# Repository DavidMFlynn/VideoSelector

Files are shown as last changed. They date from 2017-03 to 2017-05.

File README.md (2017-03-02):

# VideoSelector
Sets camera to monitor connections, RS-232, Extron Electronics MAV 88, PIC16F1847.
Created by David M. Flynn 2017
I could find one, so I built one.
The main pcb and selector switch pcbs are connected by ethernet patch cables.
Each station can select (with a gray code rotory encoder) which cammera to view.
Box 3D has a 3D printable box.

The PCBs are made with kicad.  Two of the wires on port 2 are swapped, fixed in software.
I know its unlikely anyone will want one, but it makes a good example project.

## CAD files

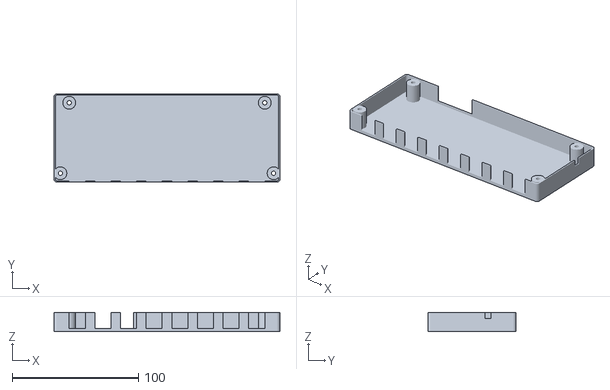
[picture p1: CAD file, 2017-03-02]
Box 3D/ProjectCaseTop.stl
179.1 x 70.1 x 15.2

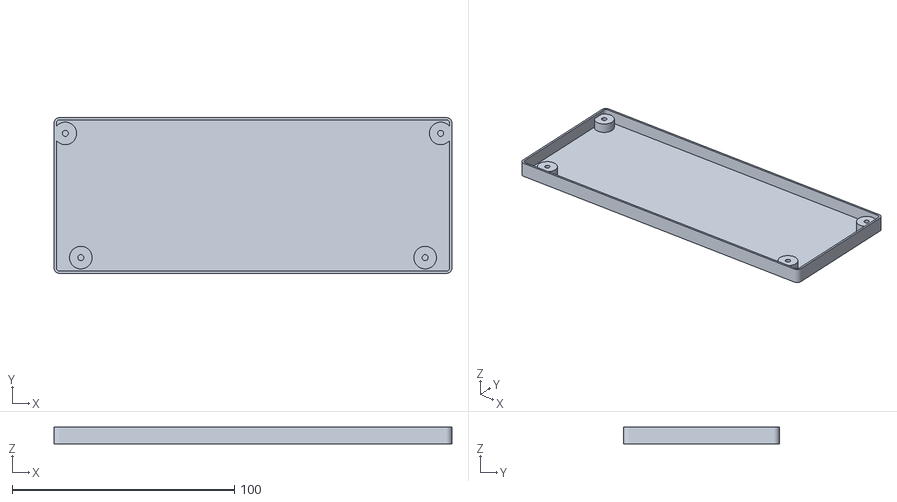
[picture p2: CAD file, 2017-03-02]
Box 3D/ProjectCaseBot.stl
179.1 x 70.1 x 7.62

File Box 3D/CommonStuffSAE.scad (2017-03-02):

// *************************************************
// filename: CommondStuffSAE.scad
//  by Dave Flynn 2015, GPL v2
// Rev: 0.9.1 2/28/2016 Some hole sizes have not been tested.
//
// This file contains constants and some common routines
// Units: Inches
// *************************************************
//  Routines for making bolt holes in parts
//  #2-56
// Bolt2ButtonHeadHole(lDepth=0.3,lHead=0.5);
// Bolt2HeadHole(lDepth=0.3,lHead=0.5);
// Bolt2Hole(depth=0.4);
// Bolt2ClearHole(depth=0.5);
//  #4-40
// Bolt4ButtonHeadHole(lDepth=0.3,lHead=0.5);
// Bolt4HeadHole(lDepth=0.3,lHead=0.5);
// Bolt4Hole(depth=0.5);
// Bolt4ClearHole(depth=0.5);
//  #6-32
// Bolt6ButtonHeadHole(lDepth=0.5,lHead=0.5);
// Bolt6HeadHole(lDepth=0.625, lAccess=0.5);
// Bolt6Hole(depth=0.625);
// Bolt6ClearHole(depth=0.5);
//  #8-32
// Bolt8ButtonHeadHole(lDepth=0.5,lHead=0.5);
// Bolt8HeadHole(lDepth=0.5, lAccess=0.5);
// Bolt8Hole(depth=0.75);
// Bolt8ClearHole(depth=0.5);
//  #10-32, #10-24, M5
// Bolt10ButtonHeadHole(lDepth=0.5,lHead=0.5);
// Bolt10HeadHole(lDepth=0.5, lAccess=0.5);
// Bolt10Hole(depth=0.75);
// Bolt10ClearHole(depth=0.75);
//  1/4"-20
// Bolt250ButtonHeadHole(lDepth=0.5,lHead=0.5);
// Bolt250HeadHole(lDepth=0.5, lAccess=0.5);
// Bolt250Hole(depth=0.75);
// Bolt250ClearHole(depth=0.75);
// *************************************************
// History
// 0.9.1 2/28/2016	Added Bolt6TapHole_r, made Bolt6_r 0.005 smaller
// 0.9 1/30/2016 	First rev'd version, Did a bunck of cleanup
// *************************************************
//ShowAllBolts(); // for visulization
//scale([25.4,25.4,25.4]) HoleTestBlock(); // Print 1 to test fit all bolts

// ********** Constants **********

OverLap=0.004;  // used to ensure manifoldness
Overlap=OverLap;
ID_Xtra=0.004;	// Added to ID to compensate for printing DMF3D

//ID_Xtra=0.008;	// Added to ID to compensate for printing Bukobot 1

Bolt2_r=0.038;
Bolt2_Head_h=0.090;
Bolt2_Head_r=0.060;
Bolt2_BtnHead_r=0.090;
Bolt2_BtnHead_h=0.045;
Bolt2_Clear_r=0.053;

Bolt4_r=0.050;
Bolt4TapHole_r=0.0445;
Bolt4_Head_r=0.091;	
Bolt4_Head_h=0.116;
Bolt4_BtnHead_r=0.120;// 0.015 over so M3 is OK
Bolt4_BtnHead_h=0.066;
Bolt4_Clear_r=0.063;

Bolt6_r=0.058;
Bolt6TapHole_r=0.055;
Bolt6_Head_r=0.125;
Bolt6_Head_h=0.140;
Bolt6_BtnHead_r=0.135;
Bolt6_BtnHead_h=0.075;
Bolt6_Clear_r=0.073;

Bolt8TapHole_r=0.068;
Bolt8_r=0.070;
Bolt8_Head_r=0.145;
Bolt8_Head_h=0.22;
Bolt8_BtnHead_r=0.188;
Bolt8_BtnHead_h=0.095;
Bolt8_Clear_r=0.090;

Bolt10TapHole_r=0.080;
Bolt10_r=0.080; // was 0.094;
Bolt10_Head_r=0.157;
Bolt10_Head_h=0.195;
Bolt10_BtnHead_r=0.190;
Bolt10_BtnHead_h=0.115;
Bolt10_Clear_r=0.105;

Bolt250TapHole_r=0.100;
Bolt250_r=0.110;
Bolt250_Head_r=0.190;
Bolt250_Head_h=0.250;
Bolt250_BtnHead_r=0.210;
Bolt250_BtnHead_h=0.135;
Bolt250_Clear_r=0.128;

// ***** #2-56 *****

module Bolt2ButtonHeadHole(lDepth=0.3,lHead=0.5){
	translate([0,0,-lDepth-Bolt2_BtnHead_h])
		cylinder(r=Bolt2_Clear_r+ID_Xtra,h=lDepth+OverLap,$fn=24);
	translate([0,0,-Bolt2_BtnHead_h])
		cylinder(r=Bolt2_BtnHead_r+ID_Xtra,h=lHead,$fn=24);
} // Bolt2ButtonHeadHole

module Bolt2HeadHole(lDepth=0.3,lHead=0.5){
	translate([0,0,-lDepth-Bolt2_Head_h])
		cylinder(r=Bolt2_Clear_r+ID_Xtra,h=lDepth+OverLap,$fn=24);
	translate([0,0,-Bolt2_Head_h])
		cylinder(r=Bolt2_Head_r+ID_Xtra,h=lHead,$fn=24);
} // Bolt2HeadHole

module Bolt2Hole(depth=0.4){
	translate([0,0,-depth-OverLap])
		cylinder(r=Bolt2_r+ID_Xtra,h=depth+OverLap*2,$fn=24);
} // Bolt2Hole

module Bolt2ClearHole(depth=0.5){
	translate([0,0,-depth-OverLap])
		cylinder(r=Bolt2_Clear_r+ID_Xtra,h=depth+OverLap*2,$fn=24);
} // BoltClearHole

// ***** #4-40 *****

module Bolt4ButtonHeadHole(lDepth=0.3,lHead=0.5){
	translate([0,0,-lDepth-Bolt4_BtnHead_h])
		cylinder(r=Bolt4_Clear_r+ID_Xtra,h=lDepth+OverLap,$fn=24);
	translate([0,0,-Bolt4_BtnHead_h])
		cylinder(r=Bolt4_BtnHead_r+ID_Xtra,h=lHead,$fn=24);
} // Bolt4ButtonHeadHole

module Bolt4HeadHole(lDepth=0.3,lHead=0.5){
	translate([0,0,-lDepth-Bolt4_Head_h])
		cylinder(r=Bolt4_Clear_r+ID_Xtra,h=lDepth+OverLap,$fn=24);
	translate([0,0,-Bolt4_Head_h])
		cylinder(r=Bolt4_Head_r+ID_Xtra,h=lHead,$fn=24);
} // Bolt4HeadHole

module Bolt4Hole(depth=0.5){
	translate([0,0,-depth-OverLap])
		cylinder(r=Bolt4_r+ID_Xtra,h=depth+OverLap*2,$fn=24);
} // Bolt4Hole

module Bolt4ClearHole(depth=0.5){
	translate([0,0,-depth-OverLap])
		cylinder(r=Bolt4_Clear_r+ID_Xtra,h=depth+OverLap*2,$fn=24);
} // BoltClearHole

// ***** #6-32 *****

module Bolt6ButtonHeadHole(lDepth=0.5,lHead=0.5){
	translate([0,0,-lDepth-Bolt6_BtnHead_h])
		cylinder(r=Bolt6_Clear_r+ID_Xtra,h=lDepth+OverLap,$fn=24);
	translate([0,0,-Bolt6_BtnHead_h])
		cylinder(r=Bolt6_BtnHead_r+ID_Xtra,h=lHead,$fn=24);
} // Bolt6ButtonHeadHole

module Bolt6ClearHole(depth=0.5){
	translate([0,0,-depth-OverLap])
		cylinder(r=Bolt6_Clear_r+ID_Xtra,h=depth+OverLap*2,$fn=24);
} // BoltClearHole

module Bolt6Hole(depth=0.625){
	translate([0,0,-depth-OverLap])
		cylinder(r=Bolt6_r+ID_Xtra,h=depth+OverLap*2,$fn=24);
} // BoltClearHole

module Bolt6HeadHole(lDepth=0.625, lAccess=0.5){
	translate([0,0,-lDepth-Bolt6_Head_h])
		cylinder(r=Bolt6_Clear_r+ID_Xtra,h=lDepth+OverLap,$fn=24);
	translate([0,0,-Bolt6_Head_h])
		cylinder(r=Bolt6_Head_r+ID_Xtra,h=Bolt6_Head_h+lAccess+OverLap,$fn=24);
} // Bolt6HeadHole

// ***** #8-32 *****

module Bolt8ButtonHeadHole(lDepth=0.5,lHead=0.5){
	translate([0,0,-lDepth-Bolt8_BtnHead_h])
		cylinder(r=Bolt8_Clear_r+ID_Xtra,h=lDepth+OverLap,$fn=24);
	translate([0,0,-Bolt8_BtnHead_h])
		cylinder(r=Bolt8_BtnHead_r+ID_Xtra,h=lHead,$fn=24);
} // Bolt8ButtonHeadHole

module Bolt8Hole(depth=0.75){
	translate([0,0,-depth-OverLap])
		cylinder(r=Bolt8_r+ID_Xtra,h=depth+OverLap*2,$fn=24);
} // Bolt8Hole

module Bolt8HeadHole(lDepth=0.5, lAccess=0.5){
	translate([0,0,-lDepth-Bolt8_Head_h])
		cylinder(r=Bolt8_Clear_r+ID_Xtra,h=lDepth+OverLap,$fn=24);
	translate([0,0,-Bolt8_Head_h])
		cylinder(r=Bolt8_Head_r+ID_Xtra,h=Bolt8_Head_h+lAccess+OverLap,$fn=24);
} // Bolt8HeadHole

module Bolt8ClearHole(depth=0.5){
	translate([0,0,-depth-OverLap])
		cylinder(r=Bolt8_Clear_r+ID_Xtra,h=depth+OverLap*2,$fn=24);
} // Bolt8Hole

// ***** #10-32, #10-24, M5 *****

module Bolt10ButtonHeadHole(lDepth=0.5,lHead=0.5){
	translate([0,0,-lDepth-Bolt10_BtnHead_h])
		cylinder(r=Bolt10_Clear_r+ID_Xtra,h=lDepth+OverLap,$fn=24);
	translate([0,0,-Bolt10_BtnHead_h])
		cylinder(r=Bolt10_BtnHead_r+ID_Xtra,h=lHead,$fn=24);
} // Bolt10ButtonHeadHole

module Bolt10Hole(depth=0.75){
	translate([0,0,-depth+OverLap])
		cylinder(r=Bolt10_r+ID_Xtra,h=depth+OverLap*2,$fn=24);
} // Bolt10Hole

module Bolt10HeadHole(lDepth=0.5, lAccess=0.5){
	translate([0,0,-lDepth-Bolt10_Head_h])
		cylinder(r=Bolt10_Clear_r+ID_Xtra,h=lDepth+OverLap,$fn=24);
	translate([0,0,-Bolt10_Head_h])
		cylinder(r=Bolt10_Head_r+ID_Xtra,h=Bolt10_Head_h+lAccess+OverLap,$fn=24);
} // Bolt10HeadHole

module Bolt10ClearHole(depth=0.75){
	translate([0,0,-depth+OverLap])
		cylinder(r=Bolt10_Clear_r+ID_Xtra,h=depth+OverLap*2,$fn=24);
} // Bolt10Hole

// ***** 1/4"-20 *****

module Bolt250ButtonHeadHole(lDepth=0.5,lHead=0.5){
	translate([0,0,-lDepth-Bolt250_BtnHead_h])
		cylinder(r=Bolt250_Clear_r+ID_Xtra,h=lDepth+OverLap,$fn=24);
	translate([0,0,-Bolt250_BtnHead_h])
		cylinder(r=Bolt250_BtnHead_r+ID_Xtra,h=lHead,$fn=24);
} // Bolt250ButtonHeadHole

module Bolt250Hole(depth=0.75){
	translate([0,0,-depth+OverLap])
		cylinder(r=Bolt250_r+ID_Xtra,h=depth+OverLap*2,$fn=24);
} // Bolt250ClearHole

module Bolt250ClearHole(depth=0.75){
	translate([0,0,-depth+OverLap])
		cylinder(r=Bolt250_Clear_r+ID_Xtra,h=depth+OverLap*2,$fn=24);
} // Bolt250ClearHole

module Bolt250HeadHole(lDepth=0.5, lAccess=0.5){
	translate([0,0,-lDepth-Bolt250_Head_h])
		cylinder(r=Bolt250_Clear_r+ID_Xtra,h=lDepth+OverLap,$fn=24);
	translate([0,0,-Bolt250_Head_h])
		cylinder(r=Bolt250_Head_r+ID_Xtra,h=Bolt250_Head_h+lAccess+OverLap,$fn=24);
} // Bolt250HeadHole

// **********************************

module ShowAllBolts(){
	translate([0,2.2,0]){ Bolt2ButtonHeadHole();
	translate([0.5,0,0]) Bolt2Hole();
	translate([1,0,0]) Bolt2ClearHole();
	translate([1.5,0,0]) Bolt2HeadHole();}

	translate([0,1.85,0]){ Bolt4ButtonHeadHole();
	translate([0.5,0,0]) Bolt4Hole();
	translate([1,0,0]) Bolt4ClearHole();
	translate([1.5,0,0]) Bolt4HeadHole();}

	translate([0,1.45,0]){ Bolt6ButtonHeadHole();
	translate([0.5,0,0]) Bolt6Hole();
	translate([1,0,0]) Bolt6ClearHole();
	translate([1.5,0,0]) Bolt6HeadHole();}

	translate([0,1,0]){ Bolt8ButtonHeadHole();
	translate([0.5,0,0]) Bolt8Hole();
	translate([1,0,0]) Bolt8ClearHole();
	translate([1.5,0,0]) Bolt8HeadHole();}

	translate([0,0.5,0]){ Bolt10ButtonHeadHole();
	translate([0.5,0,0]) Bolt10Hole();
	translate([1,0,0]) Bolt10ClearHole();
	translate([1.5,0,0]) Bolt10HeadHole();}

	translate([0,0,0]){ Bolt250ButtonHeadHole();
	translate([0.5,0,0]) Bolt250Hole();
	translate([1,0,0]) Bolt250ClearHole();
	translate([1.5,0,0]) Bolt250HeadHole();}
	
} // ShowAllBolts
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

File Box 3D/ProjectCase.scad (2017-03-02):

// **************************************************************
// Project Case (Selector 8 x 16 version)
// Revision: 1.0.0 3/1/2017
// Created: 3/1/2017
// by David M. Flynn
// units: inches
// **************************************************************
// ***** for STL output *****
// scale(25.4) BoxBottom();
// scale(25.4) rotate([180,0,0]) BoxTop();
// **************************************************************
// ***** general routines *****
// RoundRect(X=2.0,Y=1.0,Z=0.5,R=0.1);
// BoxShell(X=2.0,Y=1.0,Z=0.5,R=0.1,Wall=0.04);
// MountingBoss(X=0,Y=0,R=0.2) children;
// **************************************************************

include<CommonStuffSAE.scad>

Overlap=0.005;
IDXtra=0.008;
$fn=90;

module RoundRect(X=2.0,Y=1.0,Z=0.5,R=0.1){
	hull(){
		translate([-X/2+R,-Y/2+R,0]) cylinder(r=R, h=Z);
		translate([X/2-R,-Y/2+R,0]) cylinder(r=R, h=Z);
		translate([-X/2+R,Y/2-R,0]) cylinder(r=R, h=Z);
		translate([X/2-R,Y/2-R,0]) cylinder(r=R, h=Z);
	}// hull
	
} // RoundRect

//RoundRect();

module BoxShell(X=2.0,Y=1.0,Z=0.5,R=0.1,Wall=0.04){
	difference(){
		RoundRect(X=X,Y=Y,Z=Z,R=R);
		translate([0,0,Wall]) RoundRect(X=X-Wall*2,Y=Y-Wall*2,Z=Z,R=R-Wall);
	} // diff
	
	
} // BoxShell

//BoxShell();
PCB_t=0.063;
PCB_x=6.5;
PCB_y=2.6;
MH1=[.2,.2];
MH2=[6.3,.2];
MH3=[-0.075,PCB_y-0.2];
MH4=[PCB_x+0.075,PCB_y-0.2];
BoxWall_t=0.04;
Box_x=PCB_x+0.55;
Box_y=PCB_y+BoxWall_t*4;
BoxBot_h=0.3;
BoxTop_h=0.6;
BoxCorner_r=0.1;

module MountingBoss(X=0,Y=0,R=0.2){
	// from PCB 0,0
	
	difference(){
		translate([-PCB_x/2+X,-PCB_y/2+Y,BoxWall_t-Overlap]) cylinder(r=R,h=BoxBot_h-PCB_t-BoxWall_t);
		translate([-PCB_x/2+X,-PCB_y/2+Y,BoxBot_h-PCB_t]) children();
	} // diff
} // MountingBoss

module PCBRelPos(X=0,Y=0){
	translate([-PCB_x/2+X,-PCB_y/2+Y,0]) children();
} // PCBRelPos

module MountingBossTop(X=0,Y=0,R=0.2){
	// from PCB 0,0
	
	PCBRelPos(X=X,Y=Y)
	difference(){
		cylinder(r=R,h=BoxTop_h-Overlap);
		translate([0,0,BoxTop_h]) children();
	} // diff
} // MountingBossTop

module BoxBottom(){
	BoxShell(X=Box_x,Y=Box_y,Z=BoxBot_h,R=BoxCorner_r,Wall=BoxWall_t);
	MountingBoss(MH1[0],MH1[1],R=0.2) Bolt4Hole();
	MountingBoss(MH2[0],MH2[1],R=0.2) Bolt4Hole();
	MountingBoss(MH3[0],MH3[1],R=0.2) Bolt4Hole();
	MountingBoss(MH4[0],MH4[1],R=0.2) Bolt4Hole();
	
	// pcb
	//translate([-PCB_x/2,-PCB_y/2,BoxBot_h-PCB_t+Overlap]) cube([PCB_x,PCB_y,PCB_t]);
} // BoxBottom

//translate([0,0,-BoxBot_h]) BoxBottom();

RS232=[0.925,2.2,0.5]; // start,end,height
RJ45=[0.45,0.5,0.8,0.5]; // CL first, width, space, height
PowerCord_y=0.8;

module BoxTop(){
	difference(){
		
		translate([0,0,BoxTop_h]) mirror([0,0,1]) BoxShell(X=Box_x,Y=Box_y,Z=BoxTop_h,R=BoxCorner_r,Wall=BoxWall_t);
		
		translate([0,0,BoxTop_h]) {
		PCBRelPos(MH1[0],MH1[1]) Bolt4HeadHole();
		PCBRelPos(MH2[0],MH2[1]) Bolt4HeadHole();
		PCBRelPos(MH3[0],MH3[1]) Bolt4HeadHole();
		PCBRelPos(MH4[0],MH4[1]) Bolt4HeadHole();
		}
		
		translate([-PCB_x/2+RS232[0],-Box_y/2-Overlap,-Overlap]) cube([RS232[1]-RS232[0],BoxWall_t+Overlap*2,RS232[2]]);
		
		translate([-PCB_x/2+RJ45[0]-RJ45[1]/2,Box_y/2-BoxWall_t-Overlap,-Overlap])
			for (j=[0:7]) translate([j*RJ45[2],0,0]) cube([RJ45[1],BoxWall_t+Overlap*2,RJ45[3]]);
				
		translate([Box_x/2-BoxWall_t-Overlap,-PCB_y/2+PowerCord_y-0.1,-Overlap]) cube([BoxWall_t+Overlap*2,0.2,0.2]);
	} // diff
	
	MountingBossTop(MH1[0],MH1[1],R=0.2) Bolt4HeadHole(lDepth=BoxTop_h);
	MountingBossTop(MH2[0],MH2[1],R=0.2) Bolt4HeadHole(lDepth=BoxTop_h);
	MountingBossTop(MH3[0],MH3[1],R=0.2) Bolt4HeadHole(lDepth=BoxTop_h);
	MountingBossTop(MH4[0],MH4[1],R=0.2) Bolt4HeadHole(lDepth=BoxTop_h);

} // BoxTop 

//BoxTop();

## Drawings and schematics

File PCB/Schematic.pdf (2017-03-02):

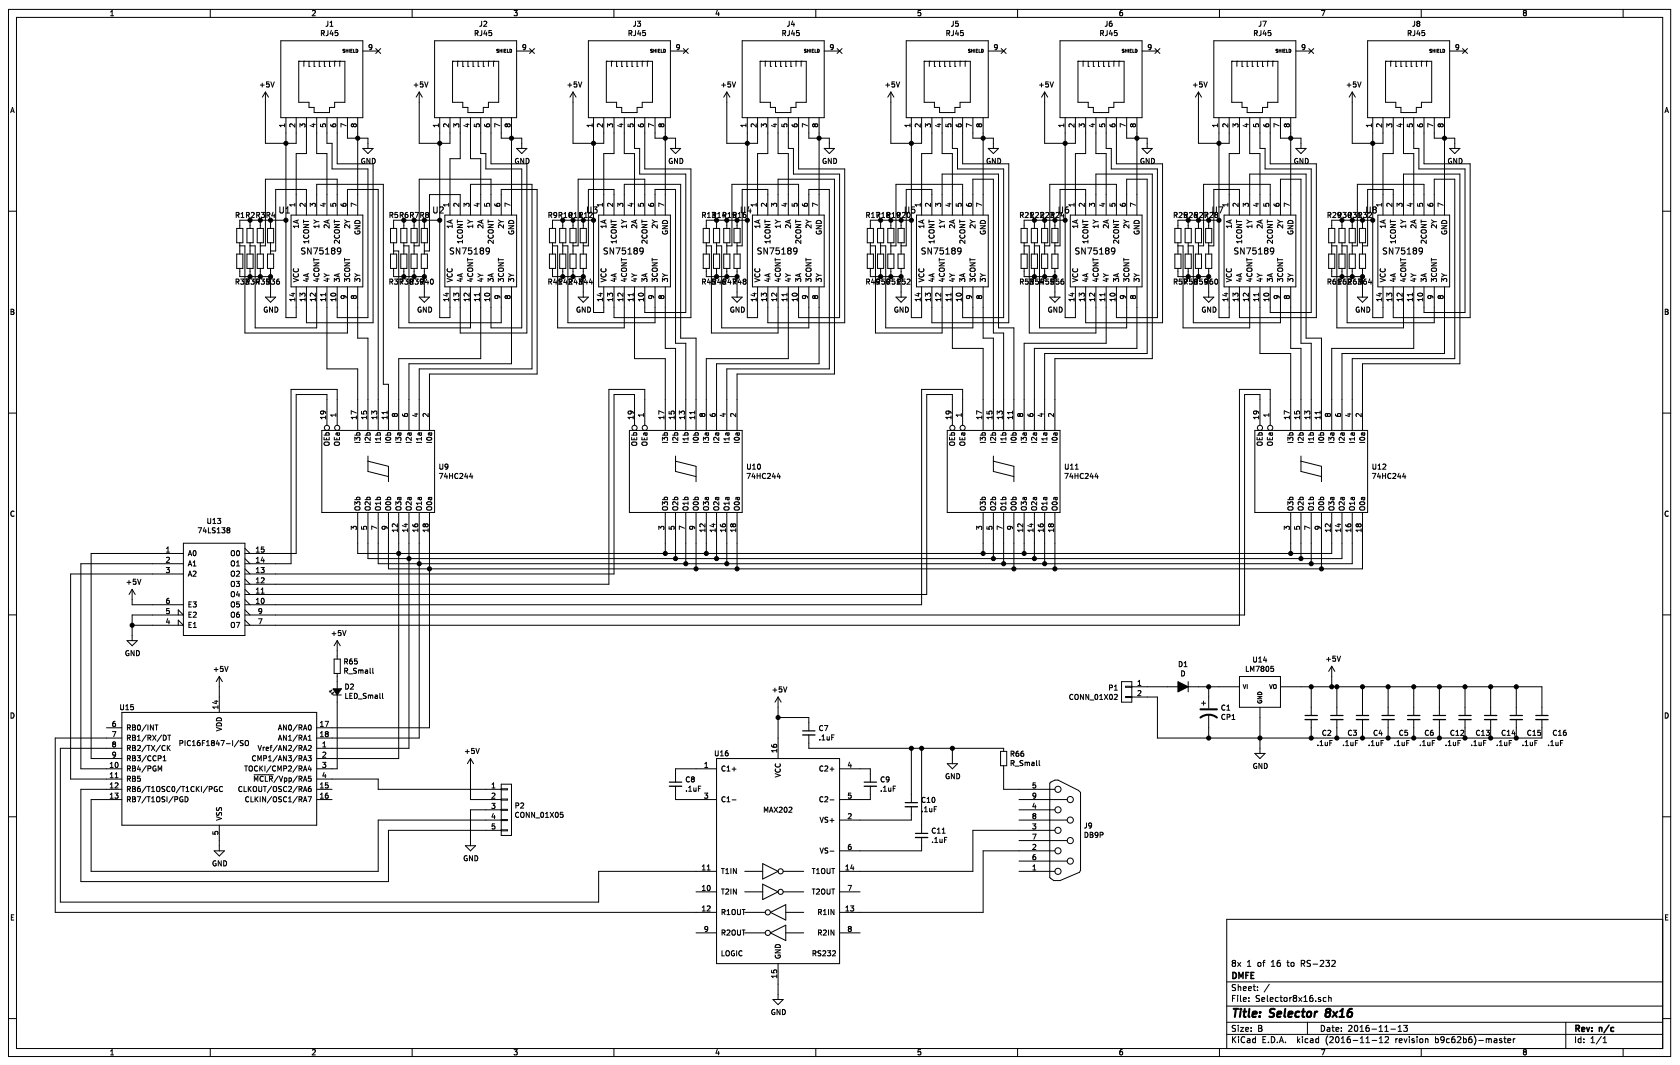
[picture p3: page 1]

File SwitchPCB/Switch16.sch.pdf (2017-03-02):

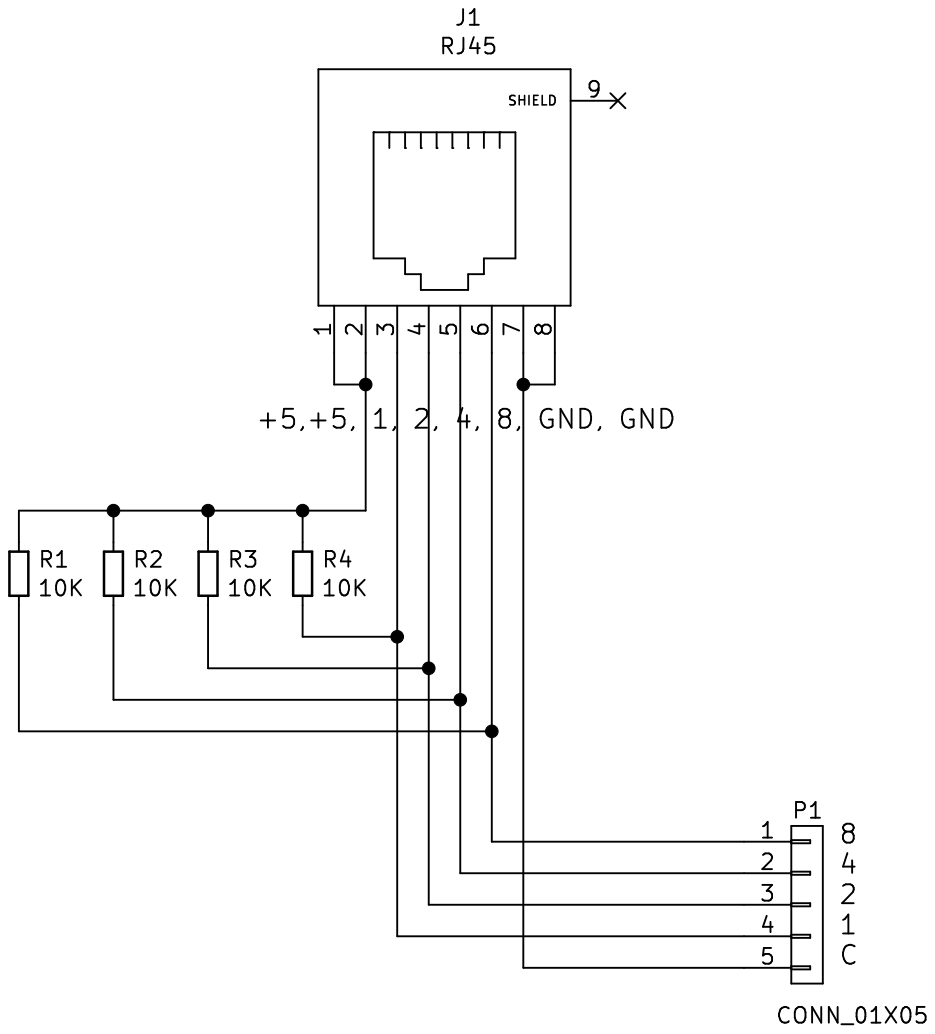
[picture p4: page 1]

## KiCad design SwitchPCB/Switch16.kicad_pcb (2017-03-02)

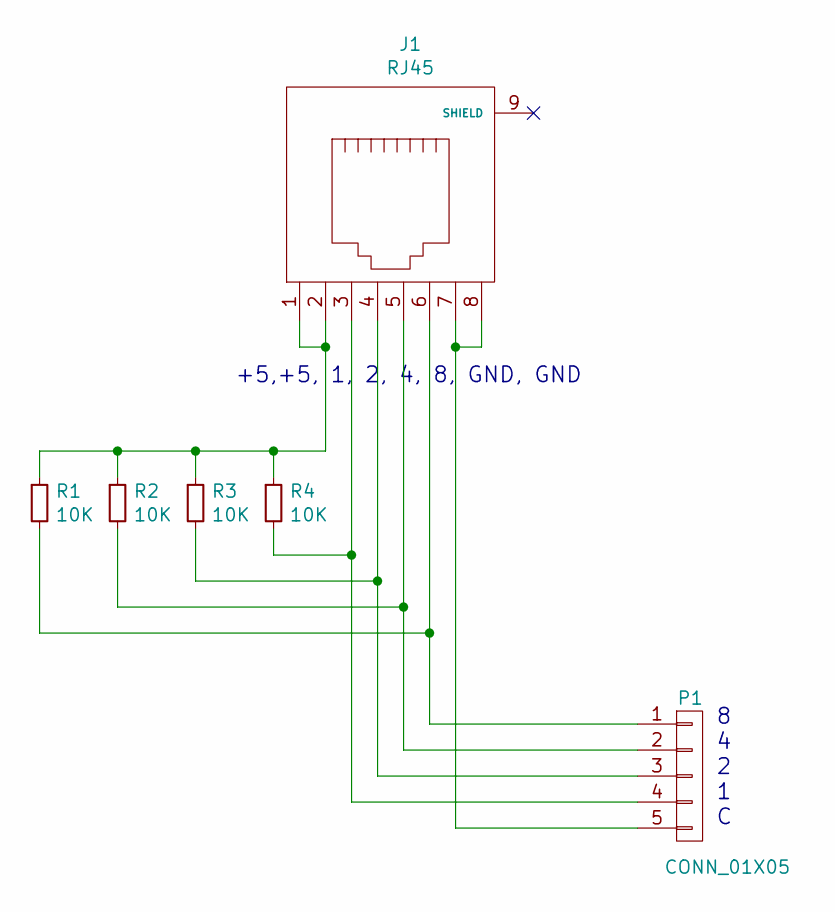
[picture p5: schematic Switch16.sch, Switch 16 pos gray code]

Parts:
J1: RJ45; RJ45_8
P1: CONN_01X05; Pin_Header_Straight_1x05
R1, R2, R3, R4: 10K; R_0805_HandSoldering

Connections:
unnamed: J1.1, J1.2, R1.1, R2.1, R3.1, R4.1
unnamed: J1.3, P1.4, R4.2
unnamed: J1.4, P1.3, R3.2
unnamed: J1.5, P1.2, R2.2
unnamed: J1.6, P1.1, R1.2
unnamed: J1.7, J1.8, P1.5

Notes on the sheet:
8 4 2 1 C
+5,+5, 1, 2, 4, 8, GND, GND

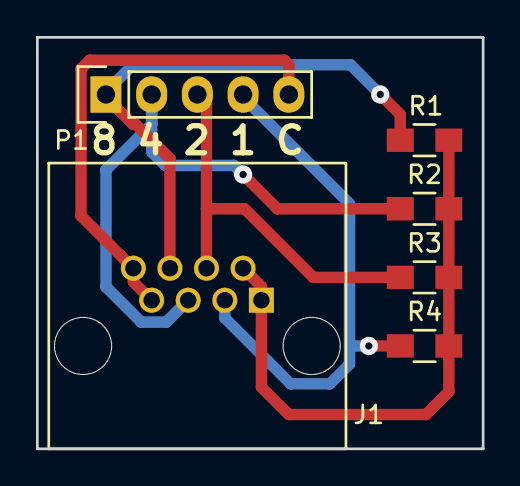
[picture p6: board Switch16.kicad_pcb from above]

Board: 2 copper layers, 24.8 x 22.9 mm, 6 parts (0 on the bottom side), 6 nets.

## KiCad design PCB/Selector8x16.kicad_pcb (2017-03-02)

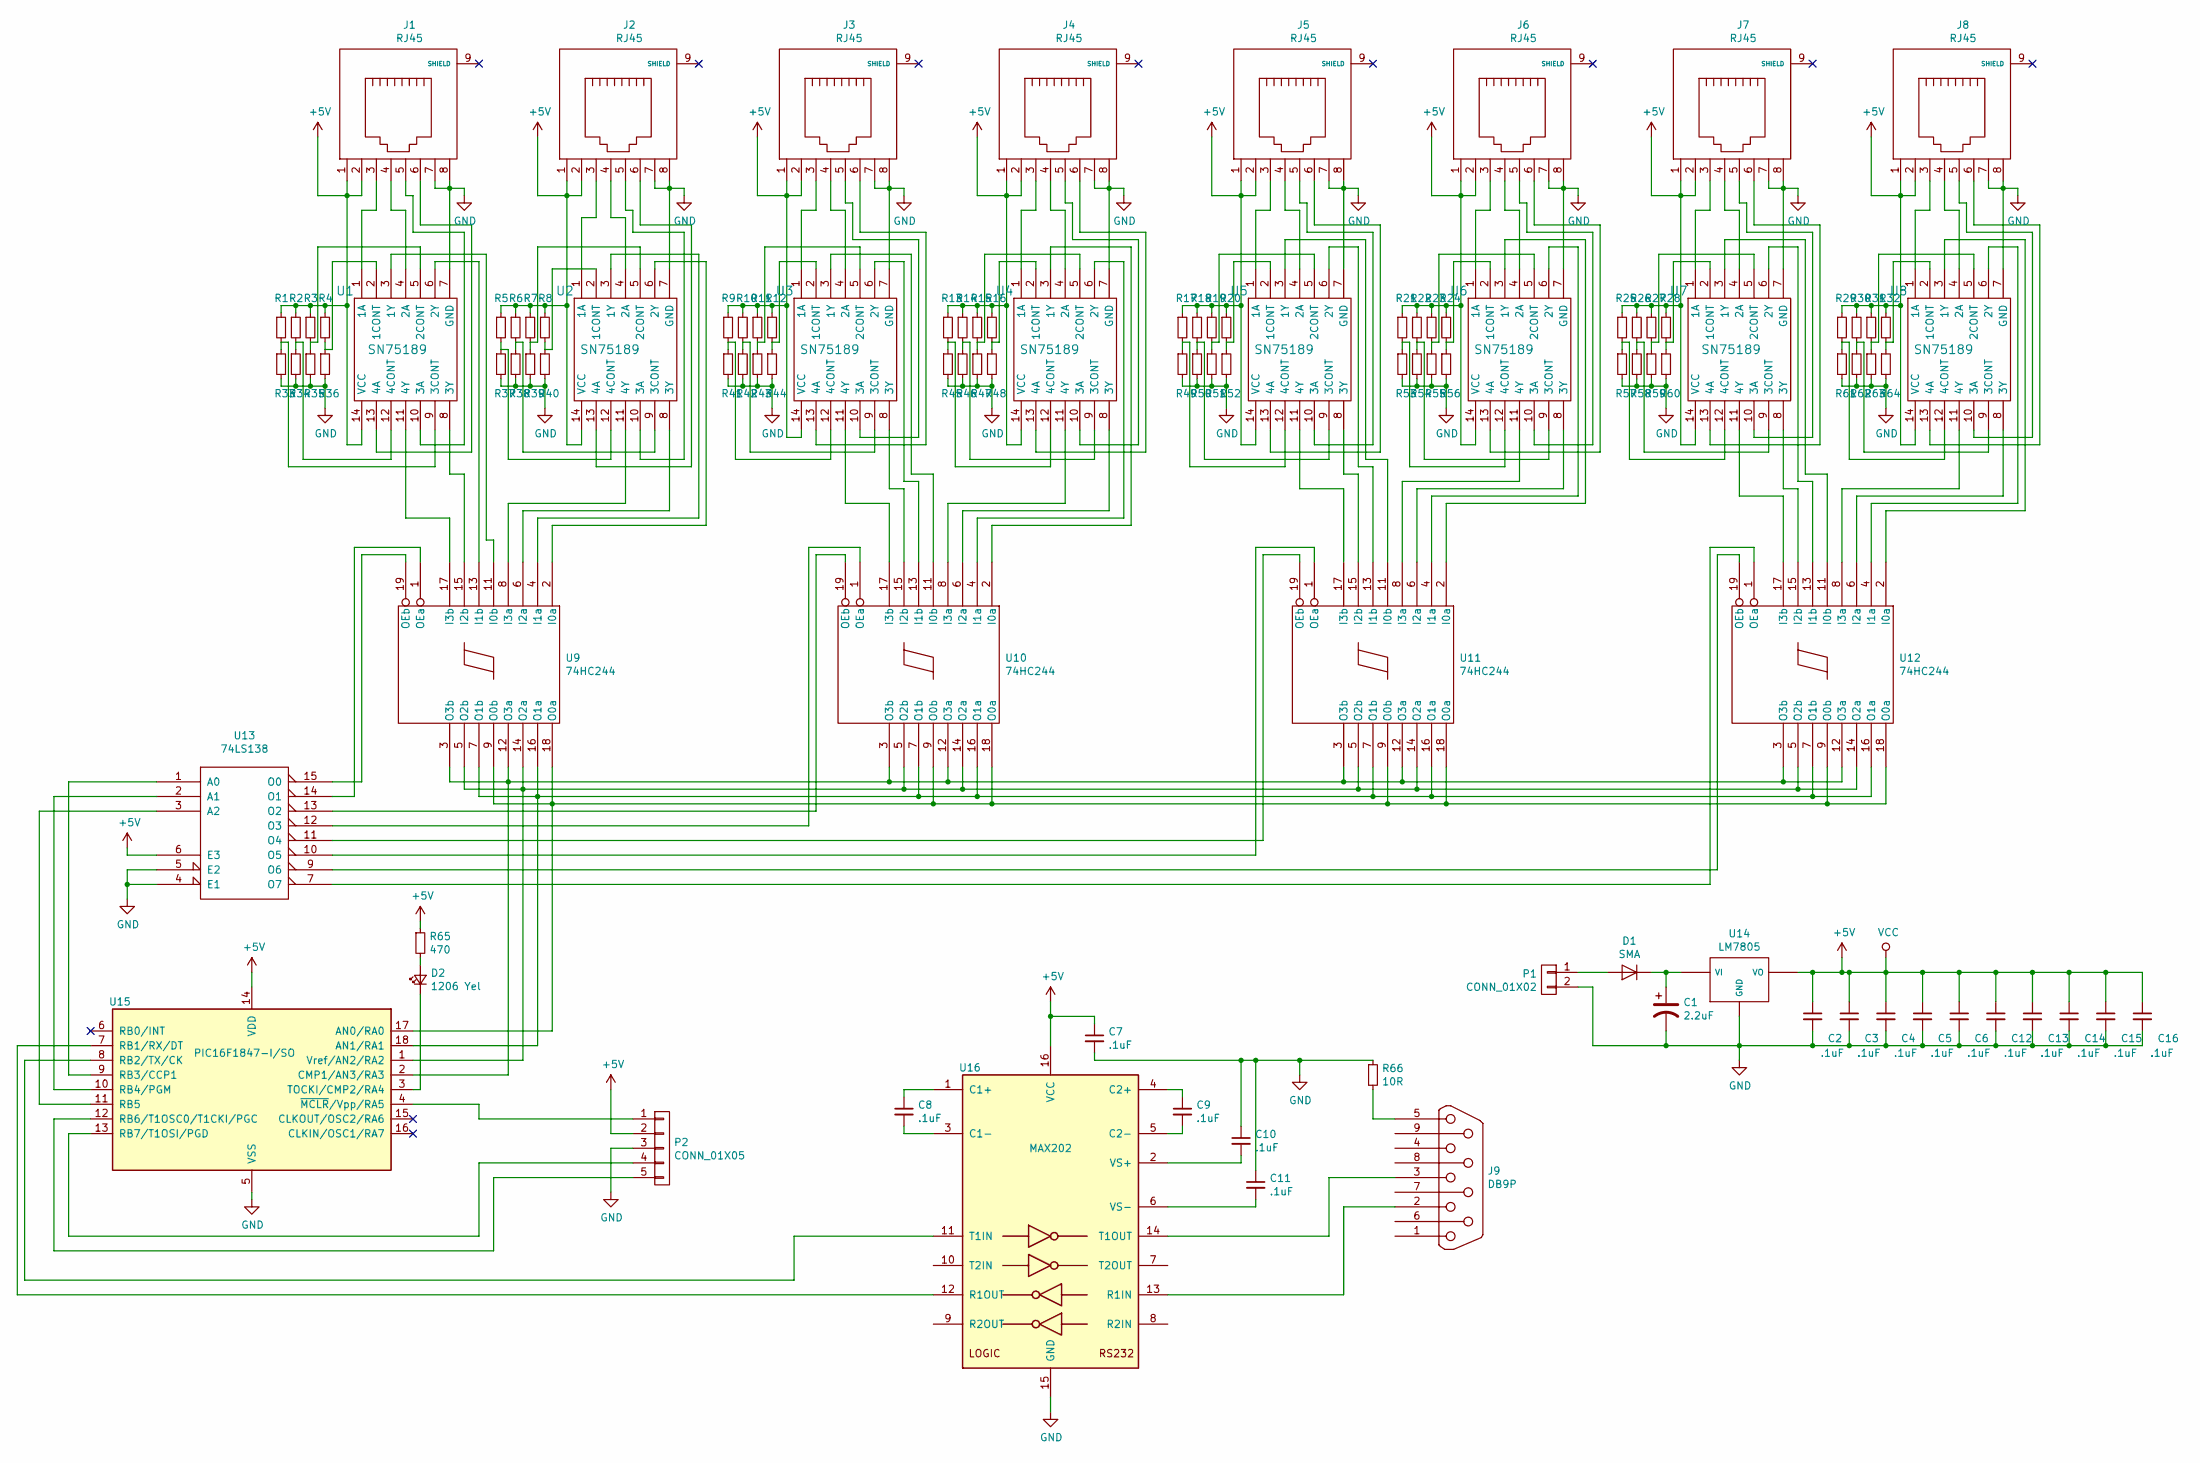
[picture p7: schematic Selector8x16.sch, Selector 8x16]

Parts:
C1: 2.2uF; C_Radial_D5_L11_P2
C2, C3, C4, C5, C6, C7, C8, C9, C10, C11, C12, C13, C14, C15, C16: .1uF; C_0805_HandSoldering
D1: SMA; SMA_Handsoldering
D2: 1206 Yel; LED_1206
J1, J2, J3, J4, J5, J6, J7, J8: RJ45
J9: DB9P; DB9MC
P1: CONN_01X02; bornier2
P2: CONN_01X05; Pin_Header_Straight_1x05
R1, R2, R3, R4, R5, R6, R7, R8, R9, R10, R11, R12, R13, R14, R15, R16, R17, R18, R19, R20, R21, R22, R23, R24, R25, R26, R27, R28, R29, R30, R31, R32, R33, R34, R35, R36, R37, R38, R39, R40, R41, R42, R43, R44, R45, R46, R47, R48, R49, R50, R51, R52, R53, R54, R55, R56, R57, R58, R59, R60, R61, R62, R63, R64: 10K; R_0805_HandSoldering
R65: 470; R_0805_HandSoldering
R66: 10R; R_0805_HandSoldering
U1, U2, U3, U4, U5, U6, U7, U8: SN75189; SOIC-14_3.9x8.7mm_Pitch1.27mm
U9, U10, U11, U12: 74HC244; SOIC-20W_7.5x12.8mm_Pitch1.27mm
U13: 74LS138; SOIC-16_3.9x9.9mm_Pitch1.27mm
U14: LM7805; TO-220_Neutral123_Horizontal
U15: PIC16F1847-I/SO; SOIC-18W_7.5x11.6mm_Pitch1.27mm
U16: MAX202; SOIC-16W_7.5x10.3mm_Pitch1.27mm

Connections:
+5V: C2.1, C3.1, C4.1, C5.1, C6.1, C7.1, C12.1, C13.1, C14.1, C15.1, C16.1, J1.1, J1.2, J2.1, J2.2, J3.1, J3.2, J4.1, J4.2, J5.1, J5.2, J6.1, J6.2, J7.1, J7.2, J8.1, J8.2, P2.2, R1.1, R2.1, R3.1, R4.1, R5.1, R6.1, R7.1, R8.1, R9.1, R10.1, R11.1, R12.1, R13.1, R14.1, R15.1, R16.1, R17.1, R18.1, R19.1, R20.1, R21.1, R22.1, R23.1, R24.1, R25.1, R26.1, R27.1, R28.1, R29.1, R30.1, R31.1, R32.1, R65.1, U1.14 (VCC), U2.14 (VCC), U3.14 (VCC), U4.14 (VCC), U5.14 (VCC), U6.14 (VCC), U7.14 (VCC), U8.14 (VCC), U9.20 (VCC), U10.20 (VCC), U11.20 (VCC), U12.20 (VCC), U13.6 (E3), U13.16 (VCC), U14.VO, U15.14 (VDD), U16.16 (VCC)
GND: C1.2, C2.2, C3.2, C4.2, C5.2, C6.2, C7.2, C10.1, C11.1, C12.2, C13.2, C14.2, C15.2, C16.2, J1.7, J1.8, J2.7, J2.8, J3.7, J3.8, J4.7, J4.8, J5.7, J5.8, J6.7, J6.8, J7.7, J7.8, J8.7, J8.8, P1.2, P2.3, R33.2, R34.2, R35.2, R36.2, R37.2, R38.2, R39.2, R40.2, R41.2, R42.2, R43.2, R44.2, R45.2, R46.2, R47.2, R48.2, R49.2, R50.2, R51.2, R52.2, R53.2, R54.2, R55.2, R56.2, R57.2, R58.2, R59.2, R60.2, R61.2, R62.2, R63.2, R64.2, R66.1, U1.7 (GND), U2.7 (GND), U3.7 (GND), U4.7 (GND), U5.7 (GND), U6.7 (GND), U7.7 (GND), U8.7 (GND), U9.10 (GND), U10.10 (GND), U11.10 (GND), U12.10 (GND), U13.4 (E1), U13.5 (E2), U13.8 (GND), U14.GND, U15.5 (VSS), U16.15 (GND)
unnamed: C1.1, D1.1 (K), U14.VI
unnamed: C8.1, U16.1 (C1+)
unnamed: C8.2, U16.3 (C1-)
unnamed: C9.1, U16.4 (C2+)
unnamed: C9.2, U16.5 (C2-)
unnamed: C10.2, U16.2 (VS+)
unnamed: C11.2, U16.6 (VS-)
unnamed: D1.2 (A), P1.1
unnamed: D2.1 (K), U15.3 (TOCKI/CMP2/RA4)
unnamed: D2.2 (A), R65.2
unnamed: J1.3, U1.1 (1A)
unnamed: J1.4, U1.4 (2A)
unnamed: J1.5, U1.10 (3A)
unnamed: J1.6, U1.13 (4A)
unnamed: J2.3, U2.1 (1A)
unnamed: J2.4, U2.4 (2A)
unnamed: J2.5, U2.10 (3A)
unnamed: J2.6, U2.13 (4A)
unnamed: J3.3, U3.1 (1A)
unnamed: J3.4, U3.4 (2A)
unnamed: J3.5, U3.10 (3A)
unnamed: J3.6, U3.13 (4A)
unnamed: J4.3, U4.1 (1A)
unnamed: J4.4, U4.4 (2A)
unnamed: J4.5, U4.10 (3A)
unnamed: J4.6, U4.13 (4A)
unnamed: J5.3, U5.1 (1A)
unnamed: J5.4, U5.4 (2A)
unnamed: J5.5, U5.10 (3A)
unnamed: J5.6, U5.13 (4A)
unnamed: J6.3, U6.1 (1A)
unnamed: J6.4, U6.4 (2A)
unnamed: J6.5, U6.10 (3A)
unnamed: J6.6, U6.13 (4A)
unnamed: J7.3, U7.1 (1A)
unnamed: J7.4, U7.4 (2A)
unnamed: J7.5, U7.10 (3A)
unnamed: J7.6, U7.13 (4A)
unnamed: J8.3, U8.1 (1A)
unnamed: J8.4, U8.4 (2A)
unnamed: J8.5, U8.10 (3A)
unnamed: J8.6, U8.13 (4A)
unnamed: J9.2, U16.13 (R1IN)
unnamed: J9.3, U16.14 (T1OUT)
unnamed: J9.5, R66.2
unnamed: P2.1, U15.4 (~MCLR~/Vpp/RA5)
unnamed: P2.4, U15.13 (RB7/T1OSI/PGD)
unnamed: P2.5, U15.12 (RB6/T1OSC0/T1CKI/PGC)
unnamed: R1.2, R33.1, U1.9 (3CONT)
unnamed: R2.2, R34.1, U1.12 (4CONT)
unnamed: R3.2, R35.1, U1.5 (2CONT)
unnamed: R10.2, R42.1, U3.9 (3CONT)
unnamed: R11.2, R43.1, U3.5 (2CONT)
unnamed: R12.2, R44.1, U3.2 (1CONT)
unnamed: R13.2, R45.1, U4.12 (4CONT)
unnamed: R14.2, R46.1, U4.9 (3CONT)
unnamed: R15.2, R47.1, U4.5 (2CONT)
unnamed: R16.2, R48.1, U4.2 (1CONT)
unnamed: R17.2, R49.1, U5.12 (4CONT)
unnamed: R18.2, R50.1, U5.9 (3CONT)
unnamed: R19.2, R51.1, U5.5 (2CONT)
unnamed: R20.2, R52.1, U5.2 (1CONT)
unnamed: R21.2, R53.1, U6.12 (4CONT)
unnamed: R22.2, R54.1, U6.9 (3CONT)
unnamed: R23.2, R55.1, U6.5 (2CONT)
unnamed: R24.2, R56.1, U6.2 (1CONT)
unnamed: R25.2, R57.1, U7.12 (4CONT)
unnamed: R26.2, R58.1, U7.9 (3CONT)
unnamed: R27.2, R59.1, U7.5 (2CONT)
unnamed: R28.2, R60.1, U7.2 (1CONT)
unnamed: R29.2, R61.1, U8.12 (4CONT)
unnamed: R30.2, R62.1, U8.9 (3CONT)
unnamed: R31.2, R63.1, U8.5 (2CONT)
unnamed: R32.2, R64.1, U8.2 (1CONT)
unnamed: R4.2, R36.1, U1.2 (1CONT)
unnamed: R5.2, R37.1, U2.12 (4CONT)
unnamed: R6.2, R38.1, U2.9 (3CONT)
unnamed: R7.2, R39.1, U2.5 (2CONT)
unnamed: R8.2, R40.1, U2.2 (1CONT)
unnamed: R9.2, R41.1, U3.12 (4CONT)
unnamed: U1.3 (1Y), U9.11 (I0b)
unnamed: U1.6 (2Y), U9.13 (I1b)
unnamed: U1.8 (3Y), U9.15 (I2b)
unnamed: U1.11 (4Y), U9.17 (I3b)
unnamed: U2.3 (1Y), U9.4 (I1a)
unnamed: U2.6 (2Y), U9.2 (I0a)
unnamed: U2.8 (3Y), U9.6 (I2a)
unnamed: U2.11 (4Y), U9.8 (I3a)
unnamed: U10.1 (OEa), U13.12 (O3)
unnamed: U4.3 (1Y), U10.2 (I0a)
unnamed: U4.6 (2Y), U10.4 (I1a)
unnamed: U4.8 (3Y), U10.6 (I2a)
unnamed: U4.11 (4Y), U10.8 (I3a)
unnamed: U3.3 (1Y), U10.11 (I0b)
unnamed: U9.3 (O3b), U9.12 (O3a), U10.3 (O3b), U10.12 (O3a), U11.3 (O3b), U11.12 (O3a), U12.3 (O3b), U12.12 (O3a), U15.2 (CMP1/AN3/RA3)
unnamed: U3.6 (2Y), U10.13 (I1b)
unnamed: U9.5 (O2b), U9.14 (O2a), U10.5 (O2b), U10.14 (O2a), U11.5 (O2b), U11.14 (O2a), U12.5 (O2b), U12.14 (O2a), U15.1 (Vref/AN2/RA2)
unnamed: U3.8 (3Y), U10.15 (I2b)
unnamed: U9.7 (O1b), U9.16 (O1a), U10.7 (O1b), U10.16 (O1a), U11.7 (O1b), U11.16 (O1a), U12.7 (O1b), U12.16 (O1a), U15.18 (AN1/RA1)
unnamed: U3.11 (4Y), U10.17 (I3b)
unnamed: U9.9 (O0b), U9.18 (O0a), U10.9 (O0b), U10.18 (O0a), U11.9 (O0b), U11.18 (O0a), U12.9 (O0b), U12.18 (O0a), U15.17 (AN0/RA0)
unnamed: U10.19 (OEb), U13.13 (O2)
unnamed: U11.1 (OEa), U13.10 (O5)
unnamed: U6.3 (1Y), U11.2 (I0a)
unnamed: U6.6 (2Y), U11.4 (I1a)
unnamed: U6.8 (3Y), U11.6 (I2a)
unnamed: U6.11 (4Y), U11.8 (I3a)
unnamed: U5.3 (1Y), U11.11 (I0b)
unnamed: U5.6 (2Y), U11.13 (I1b)
unnamed: U5.8 (3Y), U11.15 (I2b)
unnamed: U5.11 (4Y), U11.17 (I3b)
unnamed: U11.19 (OEb), U13.11 (O4)
unnamed: U12.1 (OEa), U13.7 (O7)
unnamed: U8.3 (1Y), U12.2 (I0a)
unnamed: U8.6 (2Y), U12.4 (I1a)
unnamed: U8.8 (3Y), U12.6 (I2a)
unnamed: U8.11 (4Y), U12.8 (I3a)
unnamed: U7.3 (1Y), U12.11 (I0b)
unnamed: U7.6 (2Y), U12.13 (I1b)
unnamed: U7.8 (3Y), U12.15 (I2b)
unnamed: U7.11 (4Y), U12.17 (I3b)
unnamed: U12.19 (OEb), U13.9 (O6)
unnamed: U13.1 (A0), U15.9 (RB3/CCP1)
unnamed: U13.2 (A1), U15.10 (RB4/PGM)
unnamed: U13.3 (A2), U15.11 (RB5)
unnamed: U9.1 (OEa), U13.14 (O1)
unnamed: U9.19 (OEb), U13.15 (O0)
unnamed: U15.7 (RB1/RX/DT), U16.12 (R1OUT)
unnamed: U15.8 (RB2/TX/CK), U16.11 (T1IN)

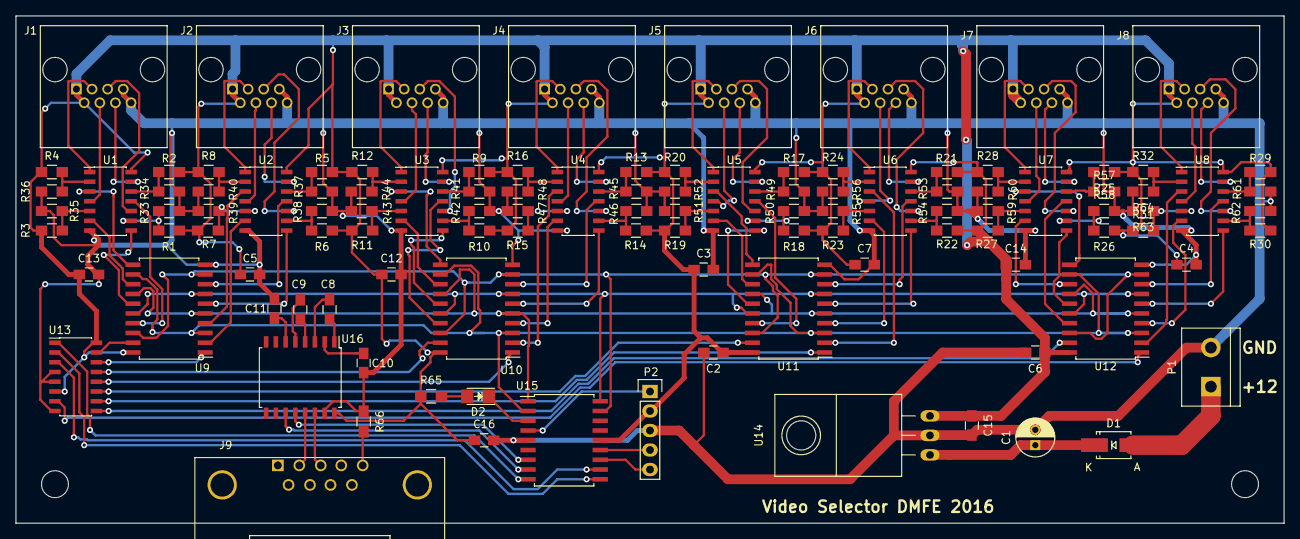
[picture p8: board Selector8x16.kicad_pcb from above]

Board: 2 copper layers, 165.1 x 66.0 mm, 113 parts (0 on the bottom side), 131 nets.

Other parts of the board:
H1, H2: MountingHole_3.5mm

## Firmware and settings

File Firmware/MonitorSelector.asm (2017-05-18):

;=========================================================================================
;
;   Filename:	MonitorSelector.asm
;   Date:	2/1/2017
;   File Version:	1.0d1
;
;    Author:	David M. Flynn
;    Company:	Oxford V.U.E., Inc.
;    E-Mail:	dflynn@oxfordvue.com
;    Web Site:	http://www.oxfordvue.com/

;=========================================================================================
;   Reads 8 1 of 16 selector switches and sends serial commands to a video switch
;
;    History:
;
; 1.0d1  2/1/2017	First code
;
;=========================================================================================
; Options
;
DefaultFlags	EQU	b'00000000'
;
;=========================================================================================
;=========================================================================================
;
;      Pic
;
; 1    RA2	D2
; 2    RA3	D3
; 3    RA4	Status LED (active low)
; 4    RA5	MCLR/vpp (P2.1)
; 5    VSS	GND
; 6    RB0	n/c
; 7    RB1/RX	RX
; 8    RB2/TX	TX
; 9    RB3	A0
;
;10    RB4	A1
;11    RB5	A2
;12    RB6/PGC	PGC (P2.4)
;13    RB7/PGD	PGD (P2.5)
;14    VDD	+5V
;15    RA6	n/c
;16    RA7	n/c
;17    RA0	D0
;18    RA1	D1
;
;=========================================================================================
;
	list	p=16f1847,r=hex,W=1	; define processor
;
	nolist
	include	p16f1847.inc	; processor specific variableis
	list
;
	__CONFIG _CONFIG1,_FOSC_INTOSC & _WDTE_ON & _MCLRE_OFF & _IESO_OFF
;
; INTOSC oscillator: I/O function on CLKIN pin
; WDT on
; PWRT disabled
; MCLR/VPP pin function is digital input
; Program memory code protection is disabled
; Data memory code protection is disabled
; Brown-out Reset enabled
; CLKOUT function is disabled. I/O or oscillator function on the CLKOUT pin
; Internal/External Switchover mode is disabled
; Fail-Safe Clock Monitor is enabled
;
	__CONFIG _CONFIG2,_WRT_ALL & _PLLEN_OFF & _LVP_OFF
;
; Write protection on
; 4x PLL disabled
; Stack Overflow or Underflow will cause a Reset
; Brown-out Reset Voltage (Vbor), low trip point selected.
; Low-voltage programming Disabled ( allow MCLR to be digital in )
;  *** must set apply Vdd before Vpp in ICD 3 settings ***
;
; '__CONFIG' directive is used to embed configuration data within .asm file.
; The lables following the directive are located in the respective .inc file.
; See respective data sheet for additional information on configuration word.
;
	constant	oldCode=0
	constant	UseEEParams=0
;
#Define	_C	STATUS,C
#Define	_Z	STATUS,Z
;
;=========================================================================================
;
	nolist
	include	F1847_Macros.inc
	list
;
;    Port A  set up
PortAValue	EQU	b'00000000'
PortADDRBits	EQU	b'11111111'	; pin 4/RA5 MSG Sw
;
#Define	Data0	PORTA,0	;Databits
#Define	Data1	PORTA,1	; 4 bit gray code
#Define	Data2	PORTA,2
#Define	Data3	PORTA,3
#Define	heartBeat	TRISA,4	; RA4:  0=LED On
			;       1=LED Off
;RA5/MCLR P2.1
;
;    Port B  set up
;
PortBValue	EQU	b'00001100'
PortBDDRBits	EQU	b'11000011'
;
#Define	RB0_In	PORTB,0	;n/c
;RB1 UART RX
;RB2 UART TX
#define	Sel_A0	LATB,3	; A0 U13.1
#define	Sel_A1	LATB,4	; A1 U13.2
#define	Sel_A2	LATB,5	; A2 U13.3
;RB6 PGC			;P2.4
;RB7 PGD			;P2.5
;
;OSCCON_Val	equ	b'01110000'	;  8 MHz
OSCCON_Val	equ	b'11110000'	; 32 MHz
;T2CON_Value	EQU	b'01001110'	;T2 On, /16 pre, /10 post
T2CON_Value	EQU	b'01001111'	;T2 On, /64 pre, /10 post
PR2_Value	EQU	.125
;
;
;============================================================
;============================================================
;
;	Constants
;
All_In	EQU	0xFF
All_Out	EQU	0x00
;
LEDTIME	EQU	d'100'	; 1.00 secondsLEDTIME
LEDErrorTime	EQU	d'10'
;
DebounceTime	EQU	d'10'
;
;========================================================
;***** VARIABLE DEFINITIONS
; there are 128 bytes of ram, Bank0 0x20..0x7F, Bank1 0xA0..0xBF
; there are 256 bytes of EEPROM starting at 0x00
; the EEPROM is not mapped into memory but
; accessed through the EEADR and EEDATA registers
;========================================================
;
;  Bank0 Ram 020h-06Fh 80 Bytes
;
	cblock	0x20
	LED_Time	
	tickcount		; Timer tick count
	ISRScratch
;
	EEAddrTemp		; EEProm address to read or write
	EEDataTemp		; Data to be writen to EEProm
;
	Timer1Lo		; 1st 16 bit timer
	Timer1Hi		; one second RX timeiout
	Timer2Lo		; 2nd 16 bit timer
	Timer2Hi		; 
	Timer3Lo		; 3rd 16 bit timer
	Timer3Hi		; GP wait timer
	Timer4Lo		; 4th 16 bit timer
	Timer4Hi		; debounce timer
;
	SysFlags		; System status
	SWFlags
	LEDFlags
;
	TXByte		;Next byte to send
	RXByte		;Last byte received
	SerFlags
	OldSWValues:8
;
	endc
;
#Define	DataReceivedFlag	SerFlags,1
#Define	DataSentFlag	SerFlags,2
;
;SysFlags bits
;
;
;=========================================================================================
;
;  Bank1 Ram 0A0h-0EFh 80 Bytes
;
;=========================================================================================
;
; Bank2 Variables:
#Define	Ser_Buff_Bank	2
	cblock	0x120
	Ser_In_Bytes		;Bytes in Ser_In_Buff
	Ser_Out_Bytes		;Bytes in Ser_Out_Buff
	Ser_In_InPtr
	Ser_In_OutPtr
	Ser_Out_InPtr
	Ser_Out_OutPtr
	Ser_In_Buff:20
	Ser_Out_Buff:20
	endc
;=========================================================================================
; Common Ram 70-7F same for all banks
; paramiter passing and temp vars
;=========================================================================================

	cblock	0x70
	Param70
	Param71
	Param72
	Param73
	Param74
	Param75
	Param76
	Param77
	Param78		; LoadFSRx working index
	Param79		; I2C message start
	Param7A		; Counter for LCD display
	Param7B
	Param7C
	Param7D
	Param7E
	Param7F
	endc
;
			;  Flags bits
;
;
;=========================================================================================
; Conditionals
;
HasISR	EQU	0x80	; Used to enable interupts
;			;    0x80=true 0x00=false
;=========================================================================================
;=========================================================================================
; ID Locations
	__idlocs	0x10d1
;
;=========================================================================================
; ***************** Reset Vector ******************
;=========================================================================================
;
	ORG	0x000	; processor reset vector
	CLRF	STATUS
	CLRF	PCLATH
	goto	Main	; go to beginning of program
;
;===============================================================================================
; Interupt Service Routine
;
; we loop through the interupt service routing every 0.008192 seconds
;
;
	ORG	0x004	; interrupt vector location
	clrf	BSR	; bank0
	clrf	PCLATH
;
; Timer 2
	BTFSS	PIR1,TMR2IF
	GOTO	TMR2_End
;Decrement timers until they are zero
; 
;
	CLRF	FSR0H
	call	DecTimer1	; Decrement timers if not zero
	call	DecTimer2
	call	DecTimer3
	call	DecTimer4
;
;-------------------------------------------------------------
; Blink LEDs
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

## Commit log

2017-03-02 Here it is...
    Done and working
    [CommonStuffSAE.scad, ProjectCase.scad, ProjectCaseBot.stl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]
2017-05-18 It didn't like the cr
    [MonitorSelector.asm]
